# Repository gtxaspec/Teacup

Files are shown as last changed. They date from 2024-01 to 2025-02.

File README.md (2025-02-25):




# TLDR: Where do i get one?
Stay Tuned!

# Teacup-Rev-C
Teacup T31 development board

Tested config as follows:

## Operating System: Thingino

## Video: Camera sensor Sony IMX327 confirmed working with 15pin PiCam module. 
```https://www.amazon.com/dp/B085VLS96S```

To initialize the camera sensor on boot issue the following command.
```fw_setenv sensor imx327``` 
This will set the sensor in the uboot environment and start the sensor on boot 

## Networking:
```https://www.amazon.com/dp/B00MYT481C```

Asix USB 2.0 ethernet adapter. This adapter works in both uboot and userland.
GMAC PHY also pinned out to a header for use with an external phy.

## Audio
Audio out and Mic tested and work

## Firmware
Thingino firmware, code is available on their Github
https://github.com/themactep/thingino-firmware/wiki

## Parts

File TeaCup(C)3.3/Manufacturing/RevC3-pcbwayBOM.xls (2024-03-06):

PCBWay Bom
Item # | *Designator | *Qty | *Mfg Part # | Description / Value | *Package/Footprint | Your Instructions / Notes | *Unit Price(1 set) | *Total | *Delivery Time | *Actual Purchase Mfg Part # | *PCBWay Note | Customer Reply | PCBWay Update
1 | C23, C24, C25, C26, C28, C30, C31, C32, C34, C35, C36, C37, C38, C39, C41, C42, C43, C44, C45, C46 | 20 |  | 100nF | C_0402_1005Metric |  | $0.021 | $0.420 |  | CC0402KRX7R9BB104
2 | C12, C15, C18, C19, C3, C6, C9 | 7 |  | 100nF | C_0603_1608Metric_Pad1.08x0.95mm_HandSolder |  | $0.056 | $0.392 |  | CC0603KRX7R8BB104
3 | C1, C10, C13, C16, C4, C7 | 6 |  | 10uF | C_0805_2012Metric_Pad1.18x1.45mm_HandSolder |  | $0.357 | $2.142 |  | CC0805KKX7R7BB106
4 | C11, C14, C17, C2, C5, C8 | 6 |  | 1uF | C_0603_1608Metric_Pad1.08x0.95mm_HandSolder |  | $0.128 | $0.768 |  | CC0603KRX7R9BB105
5 | C20, C21 | 2 |  | 12pF | C_0402_1005Metric |  | $0.065 | $0.130 |  | CC0402JRNPO9BN120
6 | C22 | 1 |  | 4.7uF | C_0603_1608Metric_Pad1.08x0.95mm_HandSolder |  | $0.887 | $0.887 |  | CC0603KRX5R6BB475
7 | R10, R11, R12, R13, R14, R24 | 6 |  | 100k | R_0603_1608Metric_Pad0.98x0.95mm_HandSolder |  | $0.021 | $0.126 |  | RC0603FR-07100KL
8 | R1, R2, R25, R3, R6, R7, R8, R9 | 8 |  | 0R | R_0603_1608Metric_Pad0.98x0.95mm_HandSolder |  | $0.017 | $0.136 |  | RC0603FR-070RL
9 | R15, R16, R17, R18, R19, R20 | 6 |  | 47k | R_0603_1608Metric_Pad0.98x0.95mm_HandSolder |  | $0.026 | $0.156 |  | RC0603FR-0747KL
10 | R4, R5 | 2 |  | 5k1 | R_0603_1608Metric_Pad0.98x0.95mm_HandSolder |  | $0.080 | $0.160 |  | RC0603FR-075K1L
11 | R21, R22 | 2 |  | 1M | R_0402_1005Metric |  | $0.082 | $0.164 |  | RC0402FR-071ML
12 | D1 | 1 | PESD5V0U2BT,215 | D_TVS_Dual_AAC | SOT-23-3 | Nexperia PESD5V0U2BT,215 https://www.lcsc.com/product-detail/Electrostatic-and-Surge-Protection-TVS-span-style-background-color-ff0-ESD-span_Nexperia-PESD5V0U2BT-215_C85399.html
13 | U1 | 1 | AZ1117IH-3.3TRG1 |  | SOT-223-3_TabPin2 | Diodes Incorporated AZ1117IH-3.3TRG1 https://www.lcsc.com/product-detail/Linear-Voltage-Regulators-LDO_Diodes-Incorporated-AZ1117H-3-3TRG1_C110474.html
14 | U2 | 1 | AZ1117CH-1.8TRG1 |  | SOT-223-3_TabPin2 | Diodes Incorporated AZ1117CH-1.8TRG1 https://www.lcsc.com/product-detail/Linear-Voltage-Regulators-LDO_Diodes-Incorporated-AZ1117IH-1-8TRG1_C3751972.html
15 | U3 | 1 | MCP1826S-0802E/DB |  | SOT-223-3_TabPin2 | Microchip Technology MCP1826S-0802E/DB https://www.lcsc.com/product-detail/Linear-Voltage-Regulators-LDO_Microchip-Tech-MCP1826S-0802E-DB_C638620.html
16 | U4 | 1 | W25Q128JVSIQ |  | SOIC-8_5.23x5.23mm_P1.27mm | https://www.lcsc.com/product-detail/NOR-FLASH_Winbond-Elec-W25Q128JVSIQ_C97521.html
17 | Y1 | 1 | XRCGB24M000F2P01R0 | 24 MHz | Crystal_SMD_2016-4Pin_2.0x1.6mm | Murata Electronics XRCGB24M000F2P01R0 https://www.mouser.com/ProductDetail/81-XRCGB24M000F2P01R | $0.858 | $0.858 | 7-10 Workdays
18 | IC1 | 1 | T31ZX |  | QFN35P900X900X90-89N-D
19 | J1 | 1 | TYPE-C-31-M-12 | USB Type-C | USB_C_Receptacle_HRO_TYPE-C-31-M-12 |  | $1.075 | $1.075
20 | J2 | 1 | DM3D-SF | SD_Card | SD_Hirose DM3D-SF | Hirose Connector DM3D-SF https://www.lcsc.com/product-detail/SD-Card-Connectors_HRS-Hirose-DM3D-SF_C719027.html
21 | J13 | 1 | SFW15R-2STE1LF |  | SFW15R2STE1LF |  | $1.796 | $1.796 | 7-10 Workdays
22 | J10 | 1 | SJ2-3573A-SMT-TR | Jack_3.5mm_PJ320D_Horizontal |  | CUI Devices SJ2-3573A-SMT-TR https://www.lcsc.com/product-detail/Audio-Connectors_CUI-Devices-SJ2-3573A-SMT-TR_C4992819.html
23 | S1 | 1 | CJS-1200TA | CJS-1200TA |  | Nidec Components CJS-1200TA https://www.lcsc.com/product-detail/Slide-Switches_Nidec-CJS-1200TA_C2921628.html
24 | S2 | 1 | TL1015AF160QG | TL1015AF160QG |  | E-Switch TL1015AF160QG https://www.mouser.com/ProductDetail/612-TL1015AF | $1.739 | $1.739 | 7-10 Workdays
25 | SW2 | 1 | JS102011SAQN | JS102011SAQN |  | C&K JS102011SAQN https://www.lcsc.com/product-detail/Slide-Switches_C-K-JS102011SAQN_C221660.html

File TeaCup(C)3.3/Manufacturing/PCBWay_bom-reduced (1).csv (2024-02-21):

item# | designator | quantity | manufacturer | mfg part# | value | pack | mount_type
1 | IC1 | 1 | 君正 Junzheng Ingenic | T31ZX | T31ZX | QFN35P900X900X90-89N-D | smt

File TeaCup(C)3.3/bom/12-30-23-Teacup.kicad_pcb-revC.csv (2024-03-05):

Id | Designator | Footprint | Quantity | Designation | Supplier and ref
1 | C19,C18,C15,C12,C9,C6,C3 | C_0603_1608Metric_Pad1.08x0.95mm_HandSolder | 7 | 100nF
2 | C2,C5,C11,C8,C17,C14 | C_0603_1608Metric_Pad1.08x0.95mm_HandSolder | 6 | 1uF
3 | SW2 | SW_SPDT_CK-JS102011SAQN | 1 | SW_SPDT
4 | R22,R21 | R_0402_1005Metric | 2 | 1M
5 | C20,C21 | C_0402_1005Metric | 2 | 12pF
6 | U2 | SOT-223-3_TabPin2 | 1 | AZ1117-1.8
7 | C1,C16,C13,C7,C10,C4 | C_0805_2012Metric_Pad1.18x1.45mm_HandSolder | 6 | 10uF
8 | U4 | SOIC-8_5.23x5.23mm_P1.27mm | 1 | W25Q32JVSS
9 | S1 | CJS-1200TA | 1 | CJS-1200TA
10 | C37,C38,C25,C30,C43,C44,C39,C23,C34,C46,C45,C42,C41,C26,C32,C31,C28,C36,C35,C24 | C_0402_1005Metric | 20 | 100nF
11 | R2,R3,R8,R1,R9,R25,R7,R6 | R_0603_1608Metric_Pad0.98x0.95mm_HandSolder | 8 | 0R
12 | J12,J11 | PinHeader_1x04_P2.54mm_Vertical | 2 | Conn_01x04_Pin
13 | R18,R17,R15,R19,R16,R20 | R_0603_1608Metric_Pad0.98x0.95mm_HandSolder | 6 | 47k
14 | J7,J6 | PinHeader_2x07_P2.54mm_Vertical | 2 | Conn_02x07_Odd_Even
15 | S2 | SW_TL1015AF160QG | 1 | TL1015AF160QG
16 | J2 | microSD_HC_Hirose_DM3D-SF | 1 | Micro_SD_Card
17 | J1 | USB_C_Receptacle_HRO_TYPE-C-31-M-12 | 1 | USB Type-C
18 | J15 | PinHeader_1x03_P2.54mm_Vertical_SMD_Pin1Left | 1 | Conn_01x03_MountingPin
19 | J10 | Jack_3.5mm_PJ320D_Horizontal | 1 | AudioJack4_Ground
20 | D1 | SOT-23-3 | 1 | D_TVS_Dual_AAC
21 | IC1 | QFN35P900X900X90-89N-D | 1 | T31ZX
22 | R13,R11,R14,R12,R10,R24 | R_0603_1608Metric_Pad0.98x0.95mm_HandSolder | 6 | 100k
23 | U3 | SOT-223-3_TabPin2 | 1 | MCP1826S
24 | U1 | SOT-223-3_TabPin2 | 1 | AZ1117-3.3
25 | J4 | PinHeader_2x08_P2.54mm_Vertical | 1 | Conn_02x08_Odd_Even
26 | J3 | USB_A_TE_292303-7_Horizontal | 1 | USB_A
27 | C22 | C_0603_1608Metric_Pad1.08x0.95mm_HandSolder | 1 | 4.7uF
28 | J9,J14 | PinHeader_1x02_P2.54mm_Vertical | 2 | Conn_01x02_MountingPin
29 | R5,R4 | R_0603_1608Metric_Pad0.98x0.95mm_HandSolder | 2 | 5k1
30 | Y1 | Crystal_SMD_2016-4Pin_2.0x1.6mm | 1 | 24 MHz
31 | J8 | BarrelJack_Wuerth_6941xx301002 | 1 | DC_IN
32 | J16 | PinHeader_1x03_P2.54mm_Vertical | 1 | Conn_01x03_MountingPin
33 | J13 | SFW15R2STE1LF | 1 | SFW15R-2STE1LF

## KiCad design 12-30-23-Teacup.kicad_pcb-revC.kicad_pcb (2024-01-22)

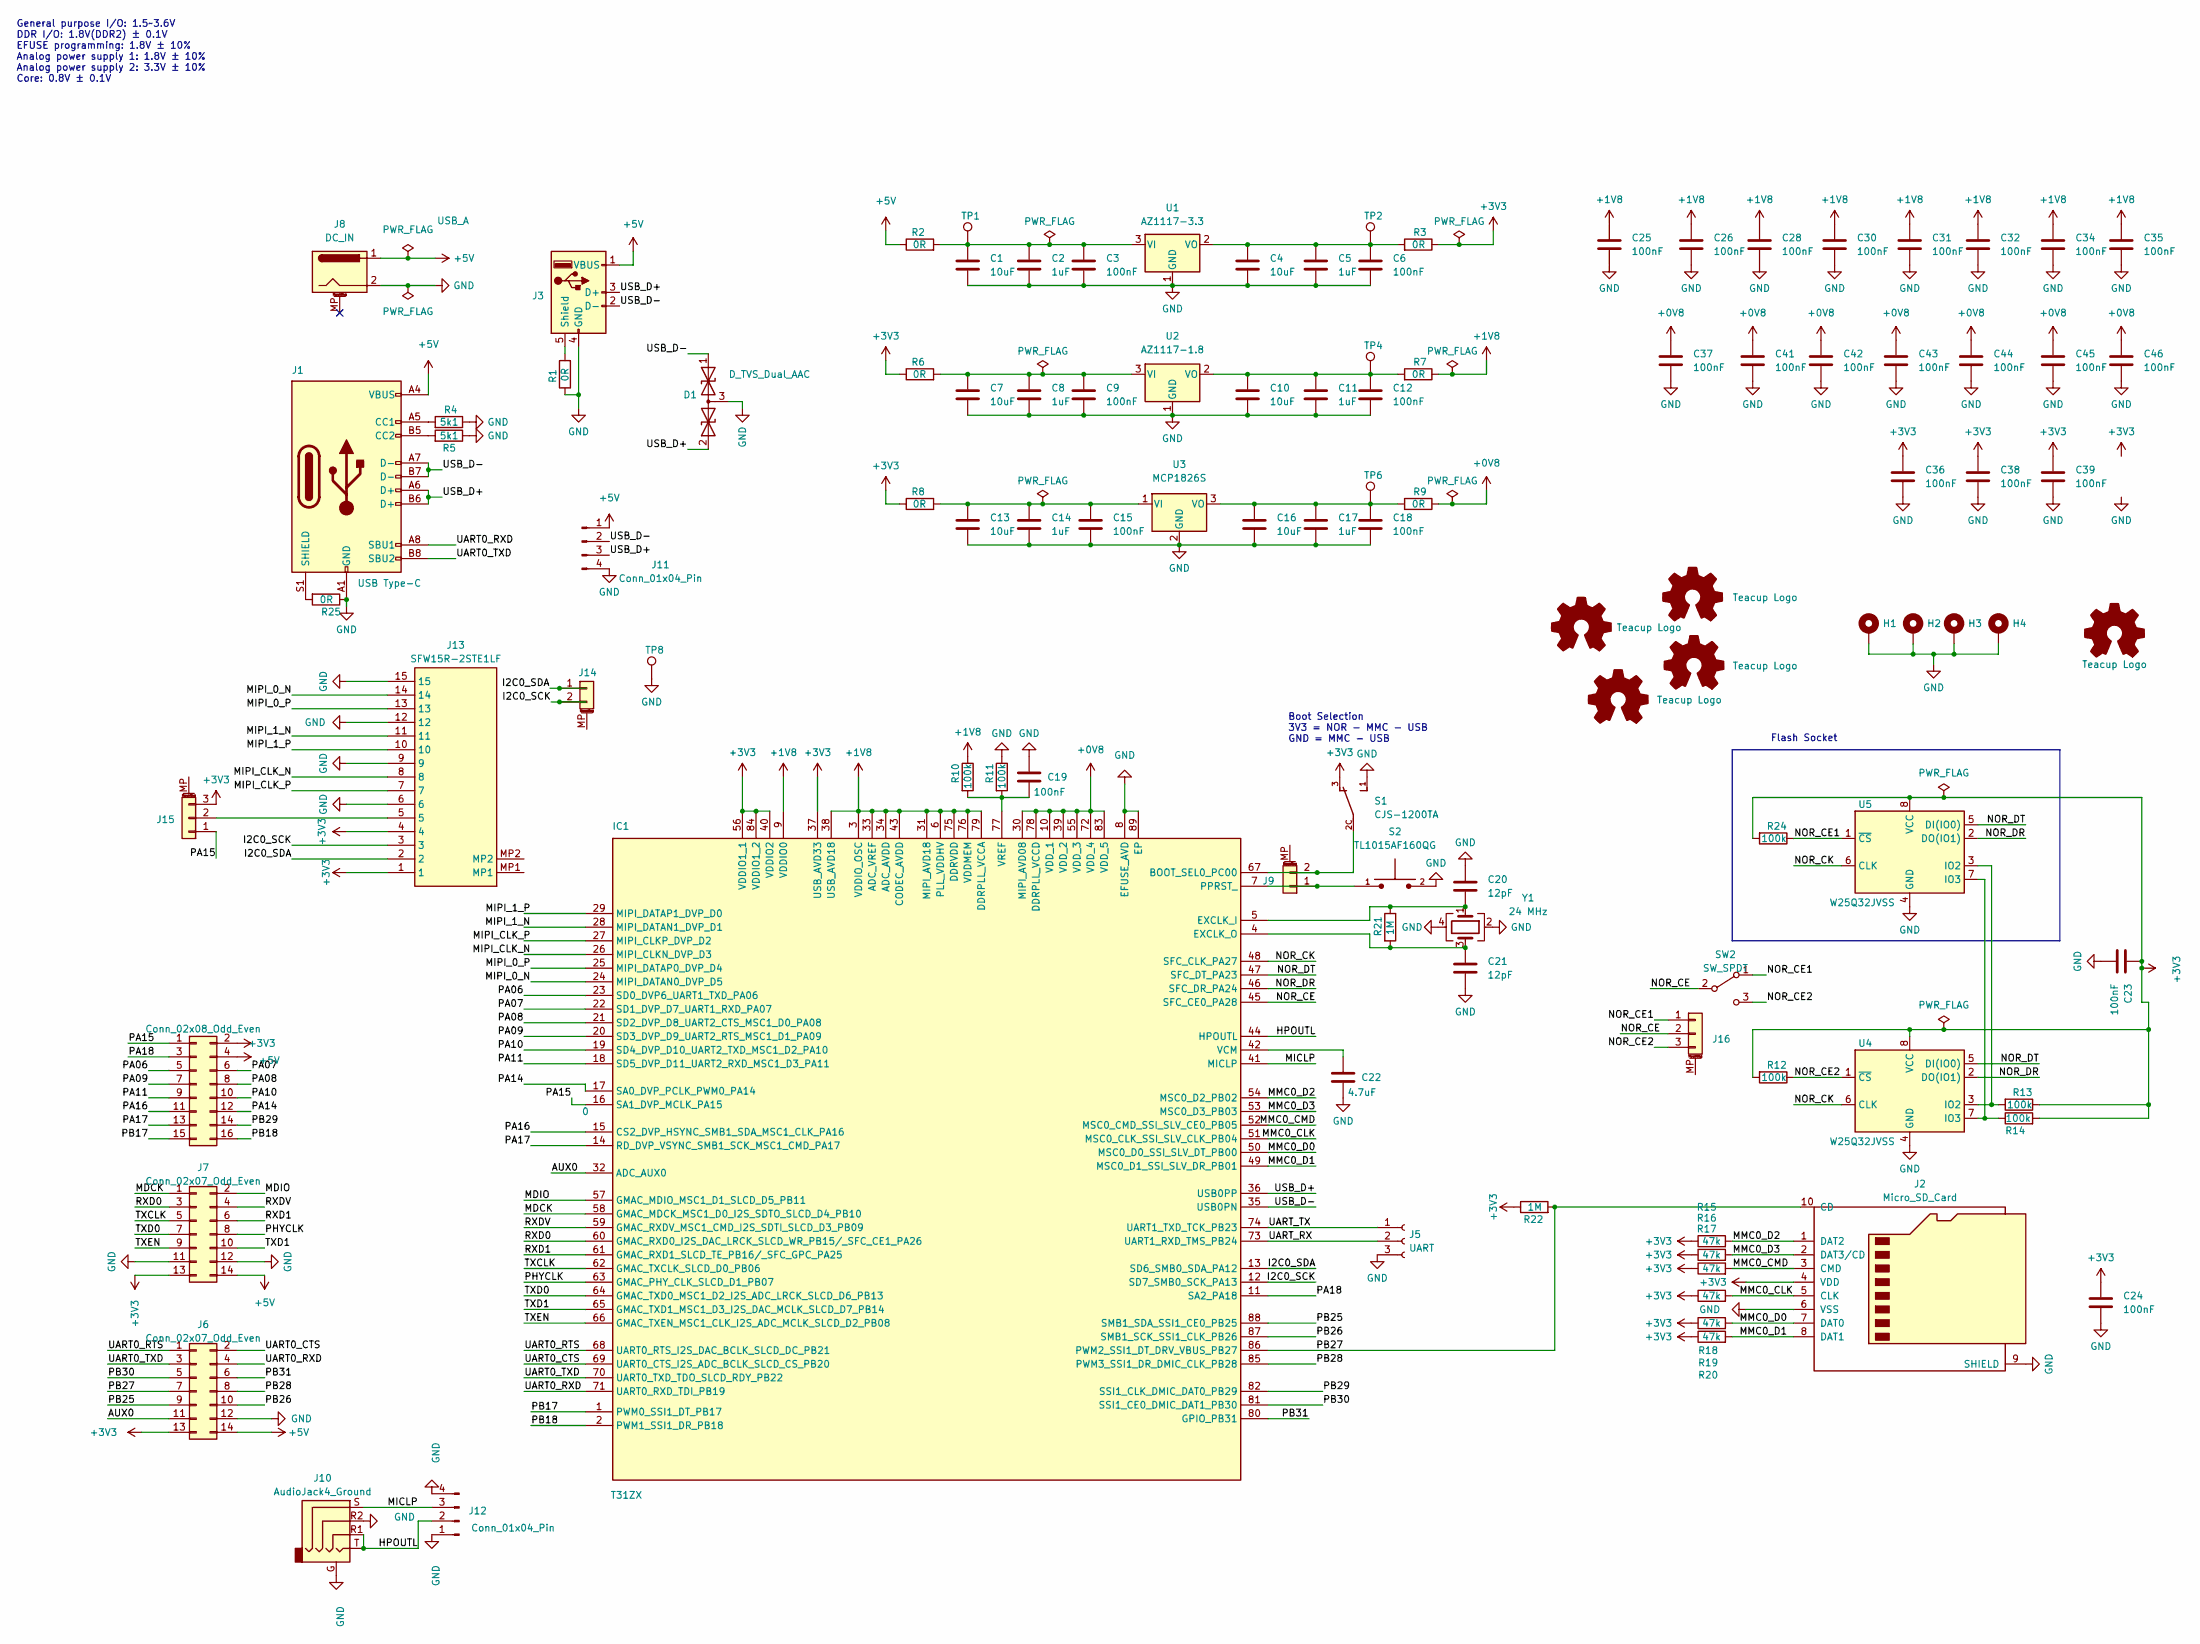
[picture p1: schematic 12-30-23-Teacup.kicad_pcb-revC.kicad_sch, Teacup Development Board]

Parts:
C1, C4, C7, C10, C13, C16: 10uF; C_0805_2012Metric_Pad1.18x1.45mm_HandSolder
C2, C5, C8, C11, C14, C17: 1uF; C_0603_1608Metric_Pad1.08x0.95mm_HandSolder
C3, C6, C9, C12, C15, C18, C19: 100nF; C_0603_1608Metric_Pad1.08x0.95mm_HandSolder
C20, C21: 12pF; C_0402_1005Metric
C22: 4.7uF; C_0603_1608Metric_Pad1.08x0.95mm_HandSolder
C23, C24, C25, C26, C28, C30, C31, C32, C34, C35, C36, C37, C38, C39, C41, C42, C43, C44, C45, C46: 100nF; C_0402_1005Metric
D1: D_TVS_Dual_AAC; SOT-23-3; Manufacturer Part Number PESD5V0U2BT,215
H1, H2, H3, H4: MountingHole_Pad; MountingHole_2.7mm_M2.5_Pad_Via
IC1: T31ZX; QFN35P900X900X90-89N-D; Mouser Part Number 870-T31ZX
J1: USB Type-C; USB_C_Receptacle_HRO_TYPE-C-31-M-12; Manufacturer Part Number TYPE-C-31-M-12 (USB4105-GF-A)
J2: Micro_SD_Card; microSD_HC_Hirose_DM3D-SF
J3: USB_A; USB_A_TE_292303-7_Horizontal
J4: Conn_02x08_Odd_Even; PinHeader_2x08_P2.54mm_Vertical
J5: UART; PinHeader_1x03_P2.54mm_Vertical
J6, J7: Conn_02x07_Odd_Even; PinHeader_2x07_P2.54mm_Vertical
J8: DC_IN; BarrelJack_Wuerth_6941xx301002
J9, J14: Conn_01x02_MountingPin; PinHeader_1x02_P2.54mm_Vertical
J10: AudioJack4_Ground; Jack_3.5mm_PJ320D_Horizontal
J11, J12: Conn_01x04_Pin; PinHeader_1x04_P2.54mm_Vertical
J13: SFW15R-2STE1LF; SFW15R2STE1LF; Mouser Part Number 649-SFW15R-2STE1LF
J15: Conn_01x03_MountingPin; PinHeader_1x03_P2.54mm_Vertical_SMD_Pin1Left
J16: Conn_01x03_MountingPin; PinHeader_1x03_P2.54mm_Vertical
LOGO1: Teacup Logo; Teacup-logo
LOGO2: Teacup Logo; OSHW-Logo_19x20mm_SilkScreen
LOGO3, LOGO4: Teacup Logo; Symbol_GNU-Logo_SilkscreenTop
LOGO5: Teacup Logo; OSHW-Logo_7.5x8mm_SilkScreen
R1, R2, R3, R6, R7, R8, R9, R25: 0R; R_0603_1608Metric_Pad0.98x0.95mm_HandSolder
R4, R5: 5k1; R_0603_1608Metric_Pad0.98x0.95mm_HandSolder
R10, R11, R12, R13, R14, R24: 100k; R_0603_1608Metric_Pad0.98x0.95mm_HandSolder
R15, R16, R17, R18, R19, R20: 47k; R_0603_1608Metric_Pad0.98x0.95mm_HandSolder
R21, R22: 1M; R_0402_1005Metric
S1: CJS-1200TA
S2: TL1015AF160QG; SW_TL1015AF160QG; PARTREV F
SW2: SW_SPDT; SW_SPDT_CK-JS102011SAQN
TP1, TP2, TP4, TP6, TP8: TestPoint; TestPoint_Pad_D1.5mm
U1: AZ1117-3.3; SOT-223-3_TabPin2; Manufacturer Part Number AZ1117IH-3.3TRG1
U2: AZ1117-1.8; SOT-223-3_TabPin2; Manufacturer Part Number AZ1117(CH)-1.8
U3: MCP1826S; SOT-223-3_TabPin2; Manufacturer Part Number MCP1826S
U4: W25Q32JVSS; SOIC-8_5.23x5.23mm_P1.27mm; Manufacturer Part Number W25Q32JVSS
U5: W25Q32JVSS; DIP-8_W7.62mm_Socket_LongPads
Y1: 24 MHz; Crystal_SMD_2016-4Pin_2.0x1.6mm; Manufacturer Part Number NX2016SA-24MHZ-EXS00A-CS07553

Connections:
+0V8: C37.1, C41.1, C42.1, C43.1, C44.1, C45.1, C46.1, IC1.10 (VDD_1), IC1.30 (MIPI_AVD08), IC1.39 (VDD_2), IC1.55 (VDD_3), IC1.72 (VDD_4), IC1.78 (DDRPLL_VCCD), IC1.83 (VDD_5), R9.1
+1V8: C25.1, C26.1, C28.1, C30.1, C31.1, C32.1, C34.1, C35.1, IC1.3 (VDDIO_OSC), IC1.6 (PLL_VDDHV), IC1.9 (VDDIO0), IC1.31 (MIPI_AVD18), IC1.33 (ADC_VREF), IC1.34 (ADC_AVDD), IC1.38 (USB_AVD18), IC1.43 (CODEC_AVDD), IC1.75 (DDRVDD), IC1.76 (VDDMEM), IC1.79 (DDRPLL_VCCA), R7.1, R10.1
+3V3: C23.1, C24.1, C36.1, C38.1, C39.1, IC1.37 (USB_AVD33), IC1.40 (VDDIO2), IC1.56 (VDDIO1_1), IC1.84 (VDDIO1_2), J1.1, J1.4, J1.5, J2.4 (VDD), J4.2, J6.13, J7.13, J13.1, J13.4, J13.5, J15.2, J15.3, R3.1, R6.1, R8.1, R12.2, R13.1, R14.2, R15.1, R16.1, R17.1, R18.1, R19.1, R20.1, R22.1, R24.2, S1.3, U4.8 (VCC), U5.8 (VCC)
+5V: J1.A4 (VBUS), J1.A9 (VBUS), J1.B4 (VBUS), J1.B9 (VBUS), J3.1 (VBUS), J4.4, J6.14, J7.14, J8.1, J11.1, R2.1
/AUX0: IC1.32 (ADC_AUX0), J6.11
/HPOUTL: IC1.44 (HPOUTL), J10.R1, J10.T, J12.2
/I2C0_SCK: IC1.12 (SD7_SMB0_SCK_PA13), J1.3, J13.3, J14.2; also elsewhere on the board
/I2C0_SDA: IC1.13 (SD6_SMB0_SDA_PA12), J1.2, J13.2, J14.1; also elsewhere on the board
/MDCK: IC1.58 (GMAC_MDCK_MSC1_D0_I2S_SDTO_SLCD_D4_PB10), J7.1
/MDIO: IC1.57 (GMAC_MDIO_MSC1_D1_SLCD_D5_PB11), J7.2
/MICLP: IC1.41 (MICLP), J10.S, J12.3
/MIPI_0_N: IC1.24 (MIPI_DATAN0_DVP_D5), J13.14
/MIPI_0_P: IC1.25 (MIPI_DATAP0_DVP_D4), J13.13
/MIPI_1_N: IC1.28 (MIPI_DATAN1_DVP_D1), J13.11
/MIPI_1_P: IC1.29 (MIPI_DATAP1_DVP_D0), J13.10
/MIPI_CLK_N: IC1.26 (MIPI_CLKN_DVP_D3), J13.8
/MIPI_CLK_P: IC1.27 (MIPI_CLKP_DVP_D2), J13.7
/MMC0_CLK: IC1.51 (MSC0_CLK_SSI_SLV_CLK_PB04), J2.5 (CLK), R18.2
/MMC0_CMD: IC1.52 (MSC0_CMD_SSI_SLV_CE0_PB05), J2.3 (CMD), R17.2
/MMC0_D0: IC1.50 (MSC0_D0_SSI_SLV_DT_PB00), J2.7 (DAT0), R19.2
/MMC0_D1: IC1.49 (MSC0_D1_SSI_SLV_DR_PB01), J2.8 (DAT1), R20.2
/MMC0_D2: IC1.54 (MSC0_D2_PB02), J2.1 (DAT2), R15.2
/MMC0_D3: IC1.53 (MSC0_D3_PB03), J2.2 (DAT3/CD), R16.2
/NOR_CE: IC1.45 (SFC_CE0_PA28), J16.2, SW2.2 (B)
/NOR_CE1: J16.1, R24.1, SW2.1 (A), U5.1 (~CS)
/NOR_CE2: J16.3, R12.1, SW2.3 (C), U4.1 (~CS)
/NOR_CK: IC1.48 (SFC_CLK_PA27), U4.6 (CLK), U5.6 (CLK)
/NOR_DR: IC1.46 (SFC_DR_PA24), U4.2 (DO(IO1)), U5.2 (DO(IO1))
/NOR_DT: IC1.47 (SFC_DT_PA23), U4.5 (DI(IO0)), U5.5 (DI(IO0))
/PA06: IC1.23 (SD0_DVP6_UART1_TXD_PA06), J4.5
/PA07: IC1.22 (SD1_DVP_D7_UART1_RXD_PA07), J4.6
/PA08: IC1.21 (SD2_DVP_D8_UART2_CTS_MSC1_D0_PA08), J4.8
/PA09: IC1.20 (SD3_DVP_D9_UART2_RTS_MSC1_D1_PA09), J4.7
/PA10: IC1.19 (SD4_DVP_D10_UART2_TXD_MSC1_D2_PA10), J4.10
/PA11: IC1.18 (SD5_DVP_D11_UART2_RXD_MSC1_D3_PA11), J4.9
/PA14: IC1.17 (SA0_DVP_PCLK_PWM0_PA14), J4.12
/PA15: IC1.16 (SA1_DVP_MCLK_PA15), J4.1, J15.1
/PA16: IC1.15 (CS2_DVP_HSYNC_SMB1_SDA_MSC1_CLK_PA16), J4.11
/PA17: IC1.14 (RD_DVP_VSYNC_SMB1_SCK_MSC1_CMD_PA17), J4.13
/PA18: IC1.11 (SA2_PA18), J4.3
/PB17: IC1.1 (PWM0_SSI1_DT_PB17), J4.15
/PB18: IC1.2 (PWM1_SSI1_DR_PB18), J4.16
/PB25: IC1.88 (SMB1_SDA_SSI1_CE0_PB25), J6.9
/PB26: IC1.87 (SMB1_SCK_SSI1_CLK_PB26), J6.10
/PB28: IC1.85 (PWM3_SSI1_DR_DMIC_CLK_PB28), J6.8
/PB29: IC1.82 (SSI1_CLK_DMIC_DAT0_PB29), J4.14
/PB30: IC1.81 (SSI1_CE0_DMIC_DAT1_PB30), J6.5
/PB31: IC1.80 (GPIO_PB31), J6.6
/PHYCLK: IC1.63 (GMAC_PHY_CLK_SLCD_D1_PB07), J7.8
/RXD0: IC1.60 (GMAC_RXD0_I2S_DAC_LRCK_SLCD_WR_PB15/_SF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), J7.3
/RXD1: IC1.61 (GMAC_RXD1_SLCD_TE_PB16/_SFC_GPC_PA25), J7.6
/RXDV: IC1.59 (GMAC_RXDV_MSC1_CMD_I2S_SDTI_SLCD_D3_PB09), J7.4
/TXCLK: IC1.62 (GMAC_TXCLK_SLCD_D0_PB06), J7.5
/TXD0: IC1.64 (GMAC_TXD0_MSC1_D2_I2S_ADC_LRCK_SLCD_D6_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), J7.7
/TXD1: IC1.65 (GMAC_TXD1_MSC1_D3_I2S_DAC_MCLK_SLCD_D7_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), J7.10
/TXEN: IC1.66 (GMAC_TXEN_MSC1_CLK_I2S_ADC_MCLK_SLCD_D2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), J7.9
/UART0_CTS: IC1.69 (UART0_CTS_I2S_ADC_BCLK_SLCD_CS_PB20), J6.2
/UART0_RTS: IC1.68 (UART0_RTS_I2S_DAC_BCLK_SLCD_DC_PB21), J6.1
/UART0_RXD: IC1.71 (UART0_RXD_TDI_PB19), J1.A8 (SBU1), J6.4
/UART0_TXD: IC1.70 (UART0_TXD_TDO_SLCD_RDY_PB22), J1.B8 (SBU2), J6.3
/UART_RX: IC1.73 (UART1_RXD_TMS_PB24), J5.2
/UART_TX: IC1.74 (UART1_TXD_TCK_PB23), J5.1
/USB_D+: D1.2 (A2), IC1.36 (USB0PP), J1.A6 (D+), J1.B6 (D+), J3.3 (D+), J11.3
/USB_D-: D1.1 (A1), IC1.35 (USB0PN), J1.A7 (D-), J1.B7 (D-), J3.2 (D-), J11.2
unnamed: IC1.67 (BOOT_SEL0_PC00), J9.2, S1.2C
unnamed: C20.2, IC1.5 (EXCLK_I), R21.1, Y1.1
unnamed: C21.1, IC1.4 (EXCLK_O), R21.2, Y1.3
unnamed: IC1.7 (PPRST_), J9.1, S2.1
unnamed: C22.1, IC1.42 (VCM)
unnamed: C19.2, IC1.77 (VREF), R10.2, R11.2
unnamed: J1.A5 (CC1), R4.2
unnamed: J1.B5 (CC2), R5.2
unnamed: J1.S1 (SHIELD), R25.2
unnamed: J3.5 (Shield), R1.2
unnamed: C1.1, C2.1, C3.1, R2.2, TP1.1, U1.3 (VI)
unnamed: C4.1, C5.1, C6.1, R3.2, TP2.1, U1.2 (VO)
unnamed: C7.1, C8.1, C9.1, R6.2, U2.3 (VI)
unnamed: C10.1, C11.1, C12.1, R7.2, TP4.1, U2.2 (VO)
unnamed: C13.1, C14.1, C15.1, R8.2, U3.1 (VI)
unnamed: C16.1, C17.1, C18.1, R9.2, TP6.1, U3.3 (VO)
unnamed: R13.2, U4.3 (IO2), U5.3 (IO2)
unnamed: R14.1, U4.7 (IO3), U5.7 (IO3)

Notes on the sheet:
Boot Selection 3V3 = NOR - MMC - USB GND = MMC - USB
Flash Socket
General purpose I/O: 1.5~3.6V DDR I/O: 1.8V(DDR2) ± 0.1V EFUSE programming: 1.8V ± 10% Analog power supply 1: 1.8V ± 10% Analog power supply 2: 3.3V ± 10% Core: 0.8V ± 0.1V

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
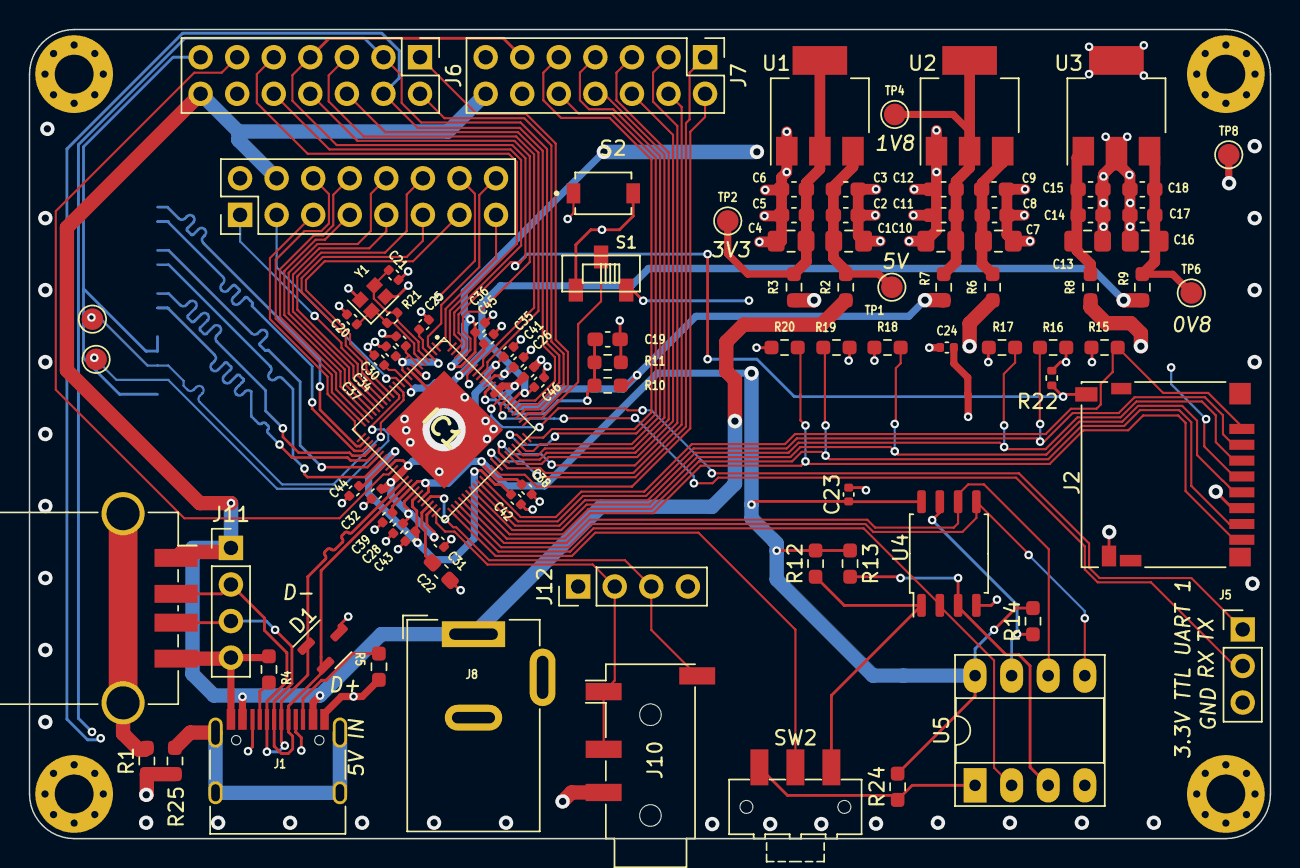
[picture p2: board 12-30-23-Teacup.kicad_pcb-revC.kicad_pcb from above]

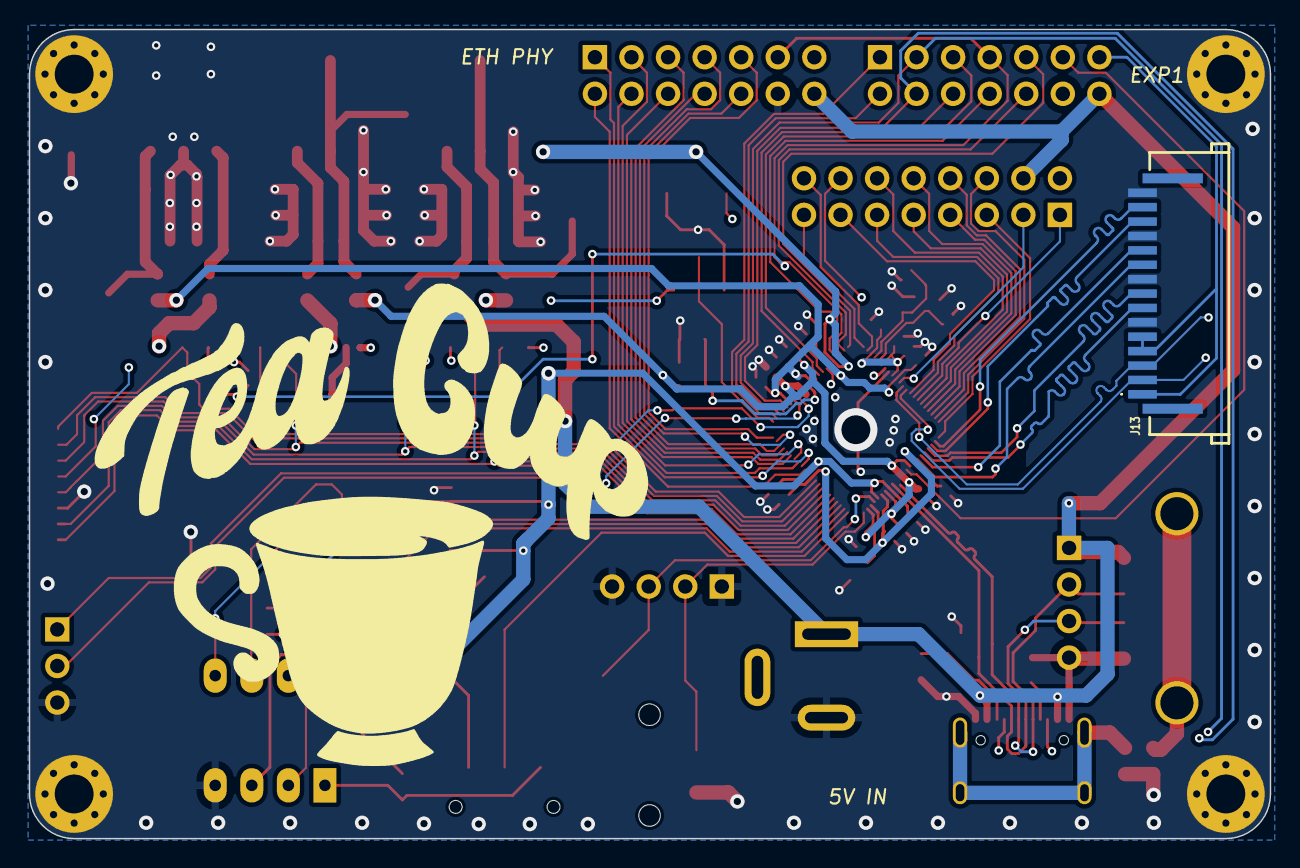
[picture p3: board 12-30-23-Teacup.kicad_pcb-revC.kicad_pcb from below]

Board: 4 copper layers, 86.2 x 56.2 mm, 101 parts (2 on the bottom side), 84 nets.

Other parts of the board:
TP7, TP9: TestPoint; TestPoint_Pad_D1.5mm

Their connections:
/I2C0_SCK: TP9.1; also elsewhere on the board
/I2C0_SDA: TP7.1; also elsewhere on the board

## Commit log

2024-01-20 Initial Commit
    Rev-C Ingenic T31 dev board
    [12-30-23-Teacup.kicad_pcb-revC.kicad_pcb, 12-30-23-Teacup.kicad_pcb-revC.kicad_sch, PCBWay_bom-reduced (1).csv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]
2024-01-22 Update 12-30-23-Teacup.kicad_pcb-revC.kicad_sch
    Update schematic
    [12-30-23-Teacup.kicad_pcb-revC.kicad_sch]
2024-01-22 Added R22 pullup resistor on PB27 to help the card detect recognition on the SD card
    Added R22 pullup resistor on PB27 to help the card detect recognition on the SD card
    [12-30-23-Teacup.kicad_pcb-revC.kicad_pcb, 12-30-23-Teacup.kicad_pcb-revC.kicad_sch]
2024-01-23 Update silkscreen labels, add solder jumper for sensor enable
    Update silkscreen labels, add solder jumper for sensor enable
    [12-30-23-Teacup.kicad_pcb-revC.kicad_sch]
2024-01-23 Add silkscreen for bootsel and reset switches
2024-01-23 Changed font on back silkscreen
2024-01-23 Add 3D render
    [12-30-23-Teacup.kicad_pcb-revC.kicad_sch]
2024-01-24 updated manufacturing gerber files
2024-02-21 Add Rev(C) 3.3
    [12-30-23-Teacup.kicad_pcb-revC.kicad_sch, PCBWay_bom-reduced (1).csv, PCBWay_positions-reduced.csv]
2024-02-21 Update Rev(C) 3.3
    [12-30-23-Teacup.kicad_pcb-revC.kicad_sch, PCBWay_bom-reduced (1).csv, PCBWay_positions-reduced.csv]
2024-02-21 update silk
    [12-30-23-Teacup.kicad_pcb-revC.kicad_sch]
2024-02-21 Adjust silk
    [12-30-23-Teacup.kicad_pcb-revC.kicad_sch]
2024-02-21 update gerbers and bom
    [12-30-23-Teacup.kicad_pcb-revC-B_Adhesive.gbr, 12-30-23-Teacup.kicad_pcb-revC-B_Courtyard.gbr, 12-30-23-Teacup.kicad_pcb-revC-B_Cu.gbr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]
2024-02-21 update BOM
2024-03-05 Added bom and centroid position file for turnkey PCBWAY
    [PCBWay_positions-complete-less-through-hole.csv, RevC3-pcbwayBOM.xls]
2024-03-05 Update README.md
    Added link for PCBWWAY turnkey service
2024-03-06 included LCSC parts in BOM
    [RevC3-pcbwayBOM.xls]
2024-03-08 added jlcpcb manufacturing files
    [JLCPCB_bom.xls, JLCPCB_positions-complete-less-through-hole.csv]
2024-03-18 Update README.md
    removed pcbway turnkey
